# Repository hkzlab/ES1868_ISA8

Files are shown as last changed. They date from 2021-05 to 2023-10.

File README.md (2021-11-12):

# ES1868F 8bit ISA Sound Card

## Introduction

This is a sound card for the ISA 8bit bus sporting the **ES1868F** chip by *ESS Technology*.

This chip provides **Sound Blaster PRO 2.0** (stereo), **OPL3** compatibility (via *ESFM*), MPU-401 support and is considered one of the [best chips](https://www.philscomputerlab.com/ess-audiodrive-es1868.html) used in clone cards.

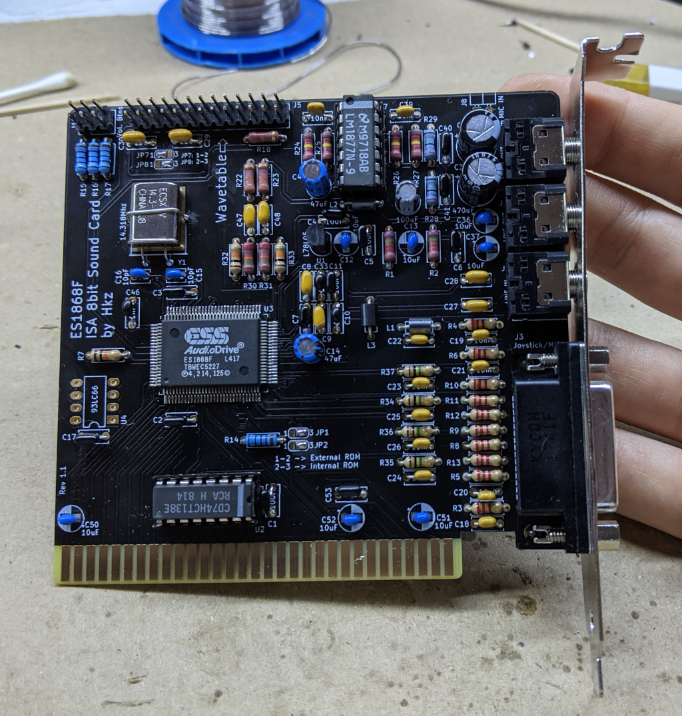
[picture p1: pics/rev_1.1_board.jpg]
Rev. 1.1 Board


This board provides the following connections:

* Speaker out (amplified)
* Line out
* Line in
* AUX in (internal header, since rev 1.2)
* Microphone in (internal header)
* Joystick port
* MIDI on Joystick port
* Wavetable header
* Volume control header

### Disclaimer

I take NO responsibility for what happens if you decide to build and use this card. Your computer might crash, catch fire or be destroyed in other nasty ways.
You're encourauged to take what you deem fit from this, and use it in your projects!

### Functionalities

✅ means I tested the functionality and it works, ❌ means I tested the functionality and found issues, ? means that the functionality has yet to be tested.

* [✅] FM Synthesis via OPL3 clone (**ESFM**)
* [✅] Digital audio playback
* [✅] Stereo (left/right channel) check (Tested with Sound Blaster PRO Test program, digitized sound mode)
* [✅] Joystick port
* [✅] Speaker Out (amplified)
* [✅] Line out
* [✅] Line in
* [✅] AUX In
* [?] Microphone in
* [✅] MIDI output via Joystick port (tested using DOSMID MPU mode on a Roland SC55)
* [✅] Wavetable daughterboard

The card was tested on:

* [✅] 286 16Mhz / DOS 6.22
* [✅] NEC V20 9.54Mhz / DOS 6.22 (Use **UNISOUND**, see **Configuration** section below)
* [✅] NEC V20 4.77Mhz / DOS 6.22 (Use **UNISOUND**, see **Configuration** section below)
* [✅] 8088 8Mhz / DOS 6.22 (Use **UNISOUND**, see **Configuration** section below)
* [✅] 8088 4.77Mhz / DOS 6.22 (Use **UNISOUND**, see **Configuration** section below)
* [✅] 486DX 40Mhz / DOS 7.1 (Use **UNISOUND**, see **Configuration** section below)
* [✅] Am5x86 40/160Mhz / DOS 7.1 (Use **UNISOUND**, see **Configuration** section below)

## Configuration

This card is jumperless and must be configured before use.
Under DOS you can us the [ESSCFG](software/ESSCFG.EXE) tool and tweak the volume via [ESSVOL](software/ESSVOL.EXE).

The **recommended** way to do this (especially under a very slow machine, like a V20/8088) is by using the [UNISOUND](https://www.vogons.org/viewtopic.php?f=62&t=72553) configurator.

It's important to add the `/XEA` parameter to `UNISOUND.COM` when using it, and remember to execute it after setting the `BLASTER` environment variable, for example with the command `SET BLASTER=A220 I5 D1 P330 T5 J201` (clearly changing the parameters depending on your setup).

**WARNING**: If you use an XT-IDE adapter at the default base address (300h), remember to set the MPU-401 base for this card to something else (like 330h)!

## Bill of Materials

**TODO**

Value of L1/L2/L3 ferrite beads is non critical. I used [these](https://www.mouser.it/ProductDetail/623-2743001112LF).

## Known Issues

### Rev 1.0

* Joystick plug "J3" silkscreen overlaps with some resistors (fixed in 1.1).
* The thread in the audio jacks I'm using (Kycon STX-3100-3CB) is flush with the bracket, so if the bracket has some bending, the plug risks to be pushed away (fixed in 1.1 by moving the connectors 0,5mm towards the edge).

## Credits

Thanks to [Sergey Kiselev](https://github.com/skiselev) for his symbol/footprint library!

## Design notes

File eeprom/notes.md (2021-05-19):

# PnP EEPROM format

This is all the datasheet has to say regarding the ES1868F EEPROM format:

```text
'A5'		Sync Byte
IRQB IRQA	Mapping for IRQB/A
IRQD IRQC	Mapping for IRQD/C
IRQF IRQE	Mapping for IRQF/E
DRQB DRQA	Mapping for DRQB/A
DRQD DRQC	Mapping for DRQD/C
PNP Reg 25h
PNP Reg 26h
```

An example is then provided:

```text
; *********************************************************
;
; Start of ESS Proprietary Header (8 bytes)
;
; *********************************************************
0A5H; PNP OK byte
059H; IRQA = 9 IRQB = 5
0A7H; IRQC = 7 IRQD = 10
0CBH; IRQE = 11 IRQF = 12
010H; DRQA = 0 DRQB = 1
053H; DRQC = 3 DRQD = 5
002H; MPU-401 part of audio, CD, DRQ latching off
00CH; GPO1/GPI are not used by Modem DMA channel or g.p.

; *********************************************************
;
; Start of PNP Resource Header
;
; *********************************************************
016H, 073H, 018H, 068H; "ESS1868" product id for ES1868
0FFH, 0FFH, 0FFH, 0FFH; serial number FFFFFFFF (not supported)
000H; header checksum
00AH, 010H, 010H; PNP 1.0, ESS version 1.0
082H, 023H, 000H; “ESS ES1868 Plug and Play AudioDrive”

; *******************************************************
;
; LOGICAL DEVICE 0 -- Configuration Ports
; 8 bytes at any I/O address that is a multiple of 8
;
; *******************************************************
015H, 016H, 073H, 000H, 000H, 000H; ESS0000
047H, 001H, 000H, 008H, 0F8H, 00FH, 008H, 008H; 800H-FF8H 8 bytes

; *******************************************************
;
; LOGICAL DEVICE 1 -- Audio Controller w/FM and MPU-401
;
; *******************************************************
015H, 016H, 073H, 018H, 068H, 000H; ESS1868

; Basic configuration 0000
031H, 000H
02AH, 002H, 008H; DMA 0: DRQ 1
02AH, 009H, 008H; DMA 1: DRQ 0 or 3
022H, 020H, 000H; INT 0: IRQ 5
04BH, 020H, 002H, 010H; 220-22F 16 bytes
04BH, 088H, 003H, 004H; 388-38B
04BH, 030H, 003H, 002H; 330-331

; Basic configuration 0001
031H, 001H
02AH, 002H, 008H; DMA 0: DRQ 1
02AH, 009H, 008H; DMA 1: DRQ 0 or 3
022H, 0A0H, 006H; INT 0: IRQ 5, 7, 9, or 10
047H, 001H, 020H, 002H, 040H, 002H, 020H, 010H; 220 or 240 16 bytes
04BH, 088H, 003H, 004H; 388-38B
047H, 001H, 000H, 003H, 030H, 003H, 030H, 002H; 300 or 330 2 bytes

; Basic configuration 0002
031H, 001H
02AH, 00BH, 008H; DMA 0: DRQ 0, 1 or 3
02AH, 00BH, 008H; DMA 1: DRQ 0, 1 or 3
022H, 0A0H, 01EH; INT 0: IRQ 5, 7, 9, 10, 11, or 12
047H, 001H, 020H, 002H, 080H, 002H, 020H, 010H; 220, 240, 260, 280 16 bytes
04BH, 088H, 003H, 004H; 388-38B
047H, 001H, 000H, 003H, 030H, 003H, 030H, 002H; 330 or 330 2 bytes

; Basic configuration 0003
031H, 001H
002H, 00BH, 008H; DMA 0: DRQ 0, 1 or 3
02AH, 00BH, 008H; DMA 1: DRQ 0, 1 or 3
022H, 0A0H, 01EH; INT 0: IRQ 5, 7, 9, 10, 11, or 12
047H, 001H, 020H, 002H, 080H, 002H, 020H, 010H; 220, 240, 260, 280 16 bytes
04BH, 088H, 003H, 004H; 388-38B
047H, 001H, 000H, 008H, 0FEH, 00FH, 002H, 002H; 800/801-FFE/FFF 2 bytes

; Basic configuration 0004
031H, 002H
02AH, 00BH, 008H; DMA 0: DRQ 0, 1 or 3
02AH, 00BH, 008H; DMA 1: DRQ 0, 1 or 3
022H, 0A0H, 01EH; INT 0: IRQ 5, 7, 9, 10, 11, or 12
047H, 001H, 020H, 002H, 080H, 002H, 020H, 010H; 220, 240, 260, 280 16 bytes
047H, 001H, 000H, 008H, 0FCH, 00FH, 004H, 004H; 800/804-FFC/FFF 4 bytes
047H, 001H, 000H, 008H, 0FEH, 00FH, 002H, 002H; 800/801-FFE/FFF 2 bytes

038H; end configurations

; *******************************************************
;
; LOGICAL DEVICE 2 -- Joystick
; Only choice is one address at 201.
;
; *******************************************************
015H, 016H, 073H, 000H, 001H, 000H; ESS0001

; Basic configuration 0000
031H, 000H
04BH, 001H, 002H, 001H; 201
; Windows95 joystick driver will only allow 200-20F!!!
; Basic configuration 0001
031H, 001H
047H, 001H, 000H, 002H, 00FH, 002H, 001H, 001H; 200/200-20F/20F 1 byte
038H; end dependent functions
01CH, 041H, 0D0H, 0B0H, 02FH; Compatible ID: PNPB02F

; *******************************************************
;
; LOGICAL DEVICE 3 -- IDE CD-ROM
; needs an IRQ (10, 11, or 12) and two separate address ranges
;
; *******************************************************
015H, 016H, 073H, 000H, 002H, 000H; ESS0002

; Basic configuration 0000
031H, 000H
022H, 000H, 010H; IRQ 12
04BH, 068H, 001H, 008H; 168-16F 8 bytes
04BH, 06EH, 003H, 002H; 36E-36F 2 bytes
; Basic configuration 0001

031H, 001H
022H, 000H, 00CH; IRQ 10 or 11
04BH, 068H, 001H, 008H; 168-16F 8 bytes
04BH, 06EH, 003H, 002H; 36E-36F 2 bytes

; Basic configuration 0002
031H, 001H
022H, 000H, 01CH; IRQ 10, 11 or 12
04BH, 0E8H, 001H, 008H; 1E8-1EF 8 bytes
04BH, 0EEH, 003H, 002H; 3EE-3EF 2 bytes

; Basic configuration 0003
031H, 001H
022H, 000H, 01CH; IRQ 10, 11 or 12
047H, 001H, 000H, 001H, 0F8H, 001H, 008H, 008H; 100/1F8-107/1FF 8 bytes
047H, 001H, 000H, 003H, 0FEH, 003H, 002H, 002H; 300/301-3FE/3FF 2 bytes

038H; end dependent functions

01CH, 041H, 0D0H, 006H, 000H	; Compatible ID: PNP0600
079H, 000H; end tag + checksum
```

## Default configuration

## Files

The default configuration that my generic board takes from startup is the following:

- Address: 220h
- IRQ: 1
- DMA: 0
- Secondary DMA: 0
- MPU401: 300h
- Joystick: Enabled

### AT93C66-dump.bin

A dump of the PnP ROM taken from a generic no-name board.

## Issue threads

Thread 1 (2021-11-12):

Values for L1, L2, and L3 are just listed as filter

washyu, 2021-11-12:
In the schematic and on the silkscreen the value is just listed as Filter.  Could you please supply the value i really want to finish building this card but I am stuck because of this.

hkzlab, 2021-11-12:
As shown on the schematics and in photo those are ferrite beads. Value is absolutely non critical, a simple jumper made with the leg of a resistor would probably work.
You can use these: https://www.mouser.it/ProductDetail/623-2743001112LF

Closed 2021-11-12.

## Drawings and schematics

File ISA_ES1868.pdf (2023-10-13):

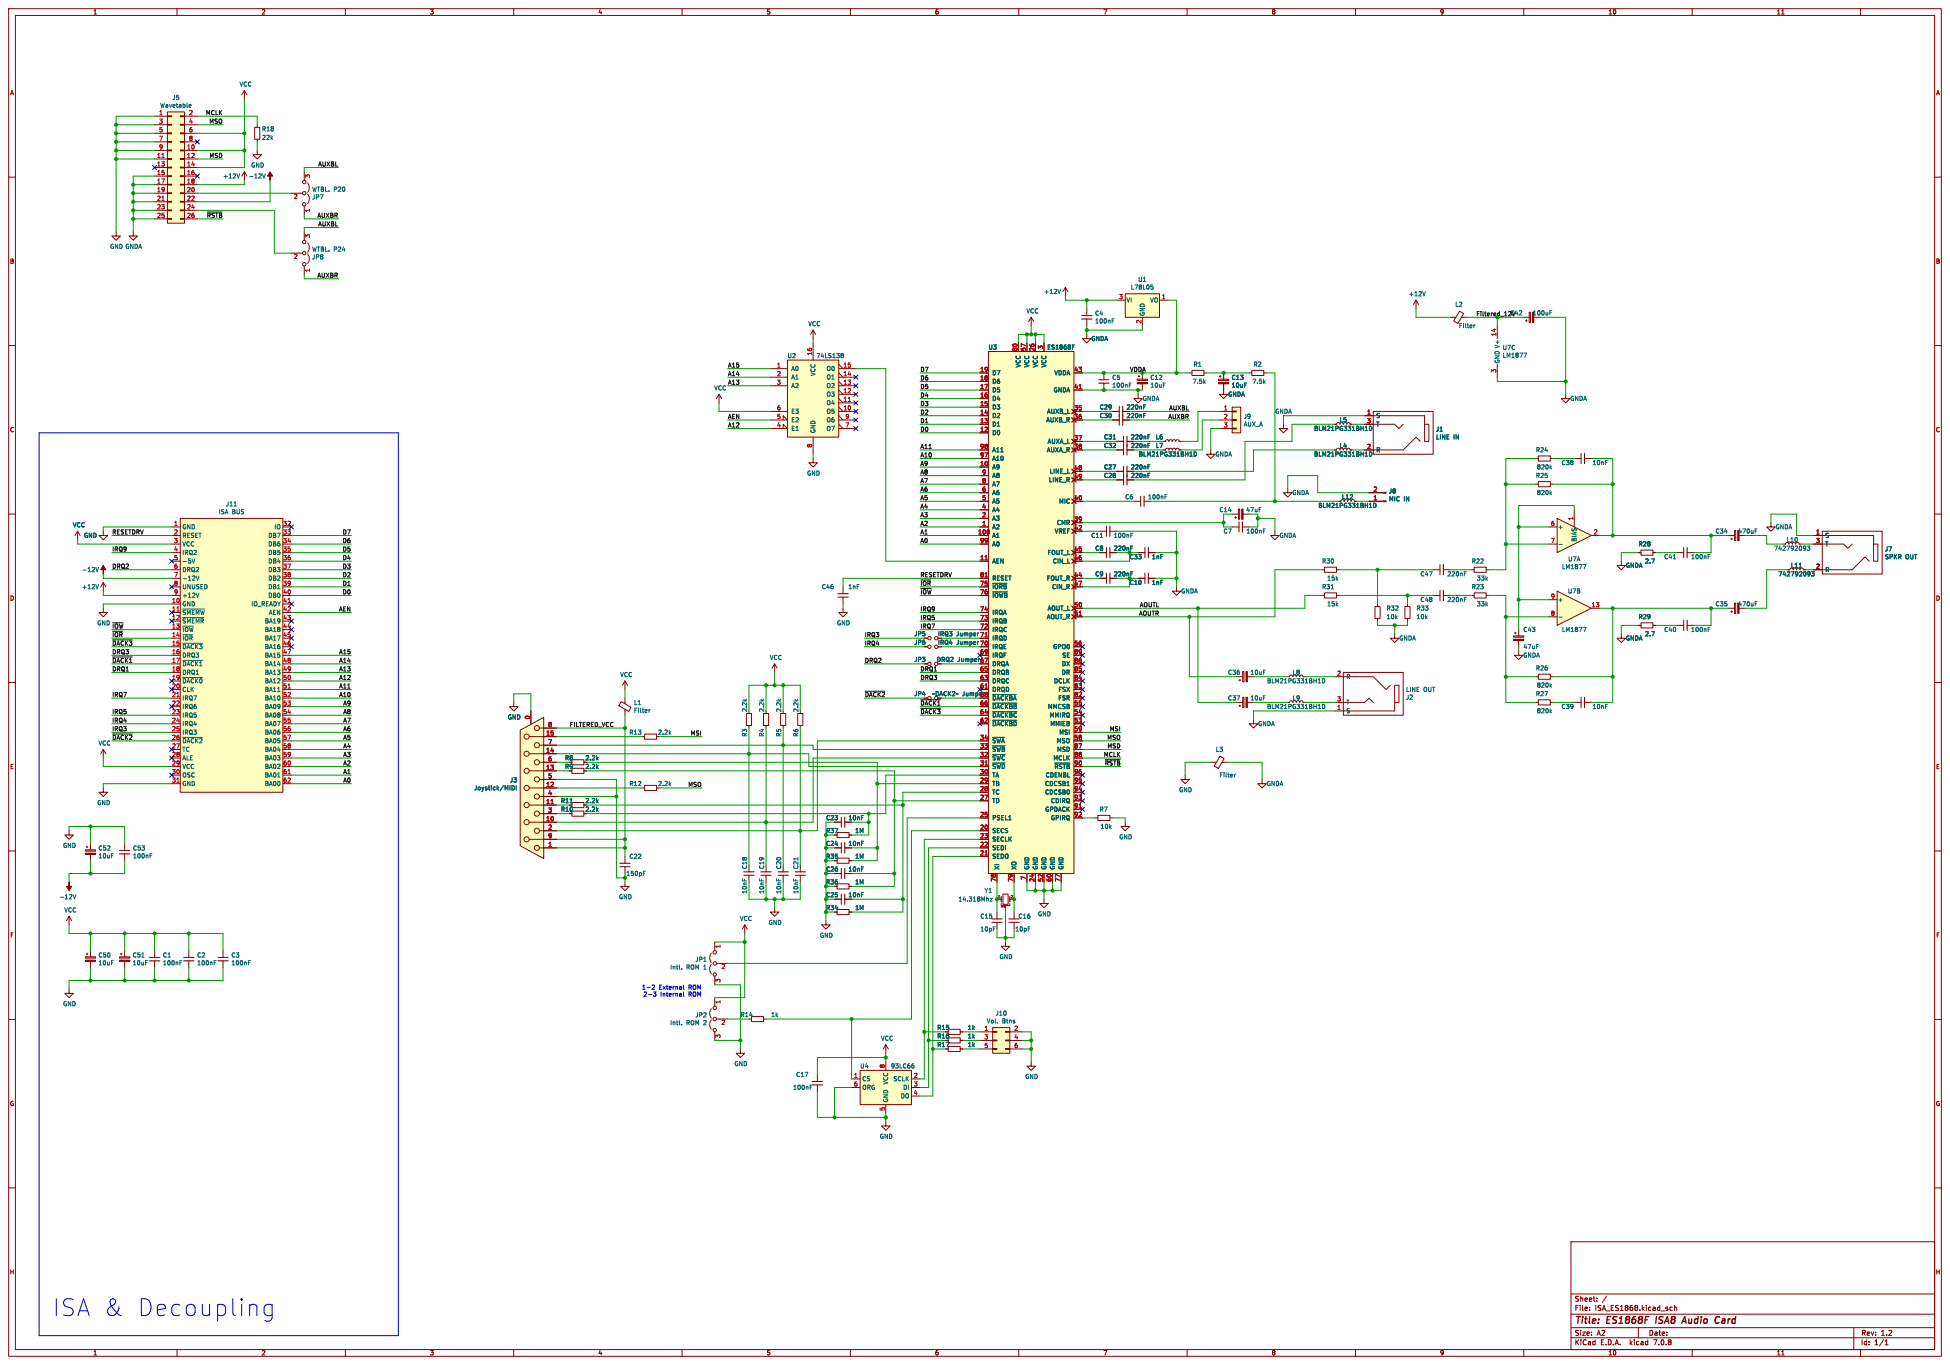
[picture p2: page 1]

3 TA 30 ~{SWD} 31 ~{SWC} 32 ~{SWB} 33 ~{SWA} 34

ISA BUS
GND 1 GND 10 ~{SMEMW} 11 ~{SMEMR} 12 ~{IOW} 13 ~{IOR} 14 ~{DACK3} 15 DRQ3 16 ~{DACK1} 17 DRQ1 18 ~{DACK0} 19 RESET 2 CLK 20
IRQ3 25 ~{DACK2} 26 TC 27 ALE 28 VCC 29 VCC 3 OSC 30 GND 31
IO_READY 41 AEN 42 BA19 43 BA18 44 BA17 45 BA16 46 BA15 47 BA14 48 BA13 49

~{RSTB} MCLK MSI MSD MSO

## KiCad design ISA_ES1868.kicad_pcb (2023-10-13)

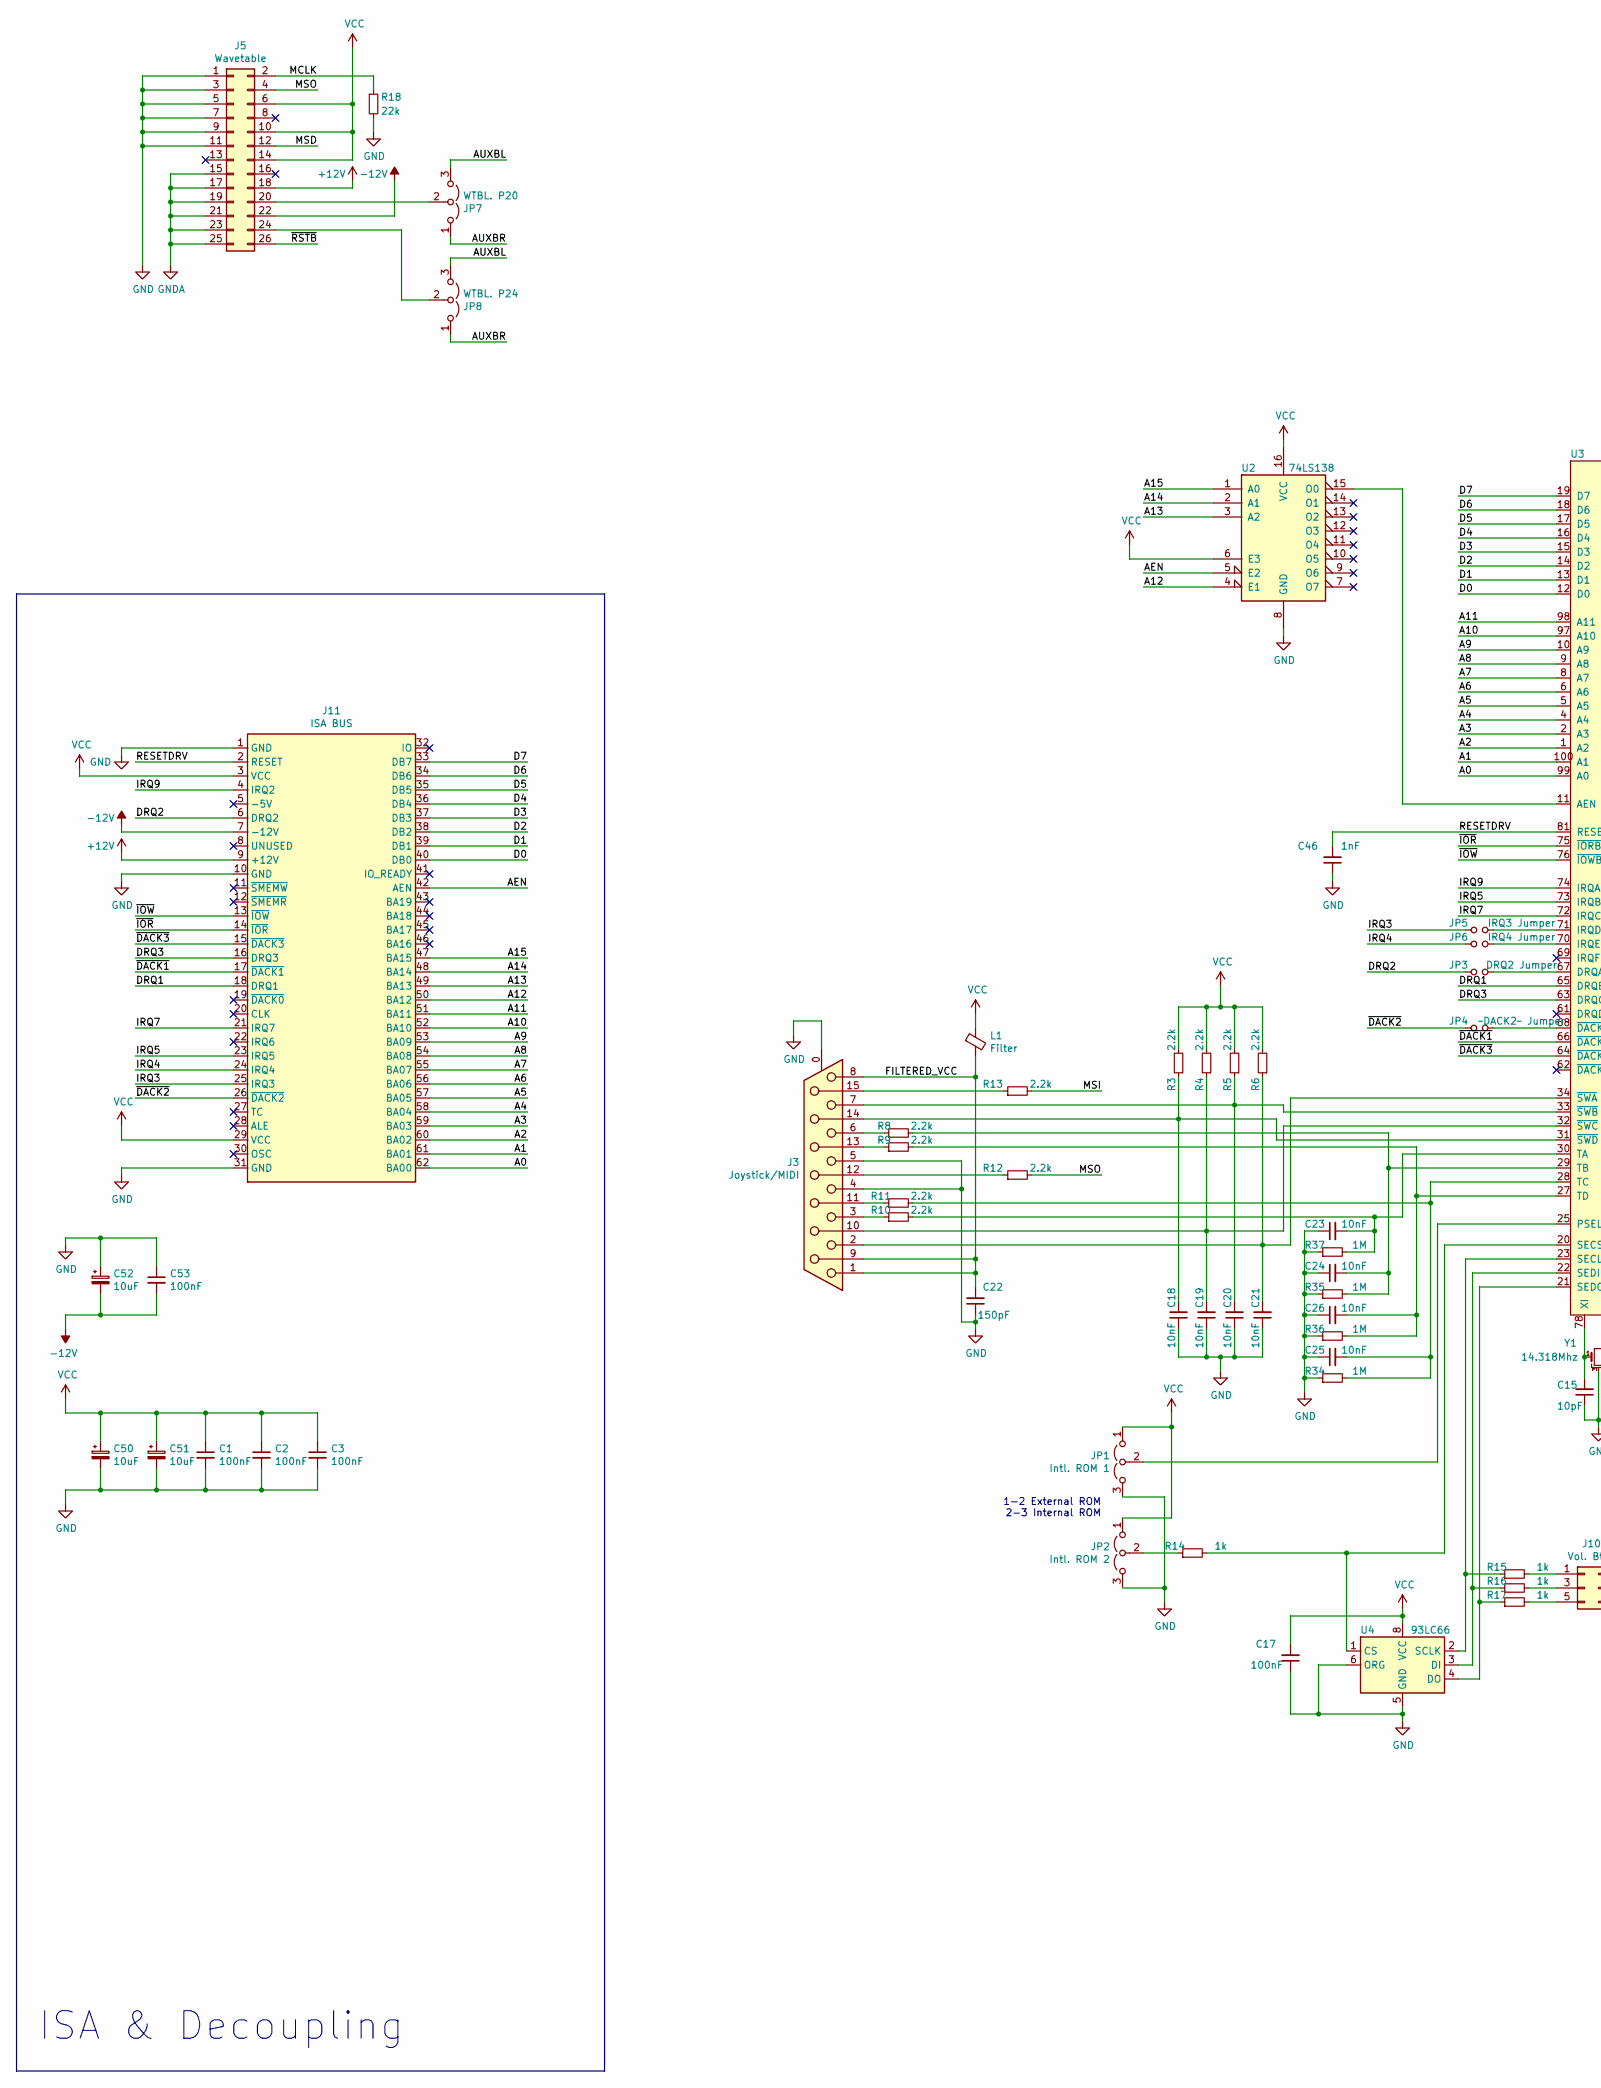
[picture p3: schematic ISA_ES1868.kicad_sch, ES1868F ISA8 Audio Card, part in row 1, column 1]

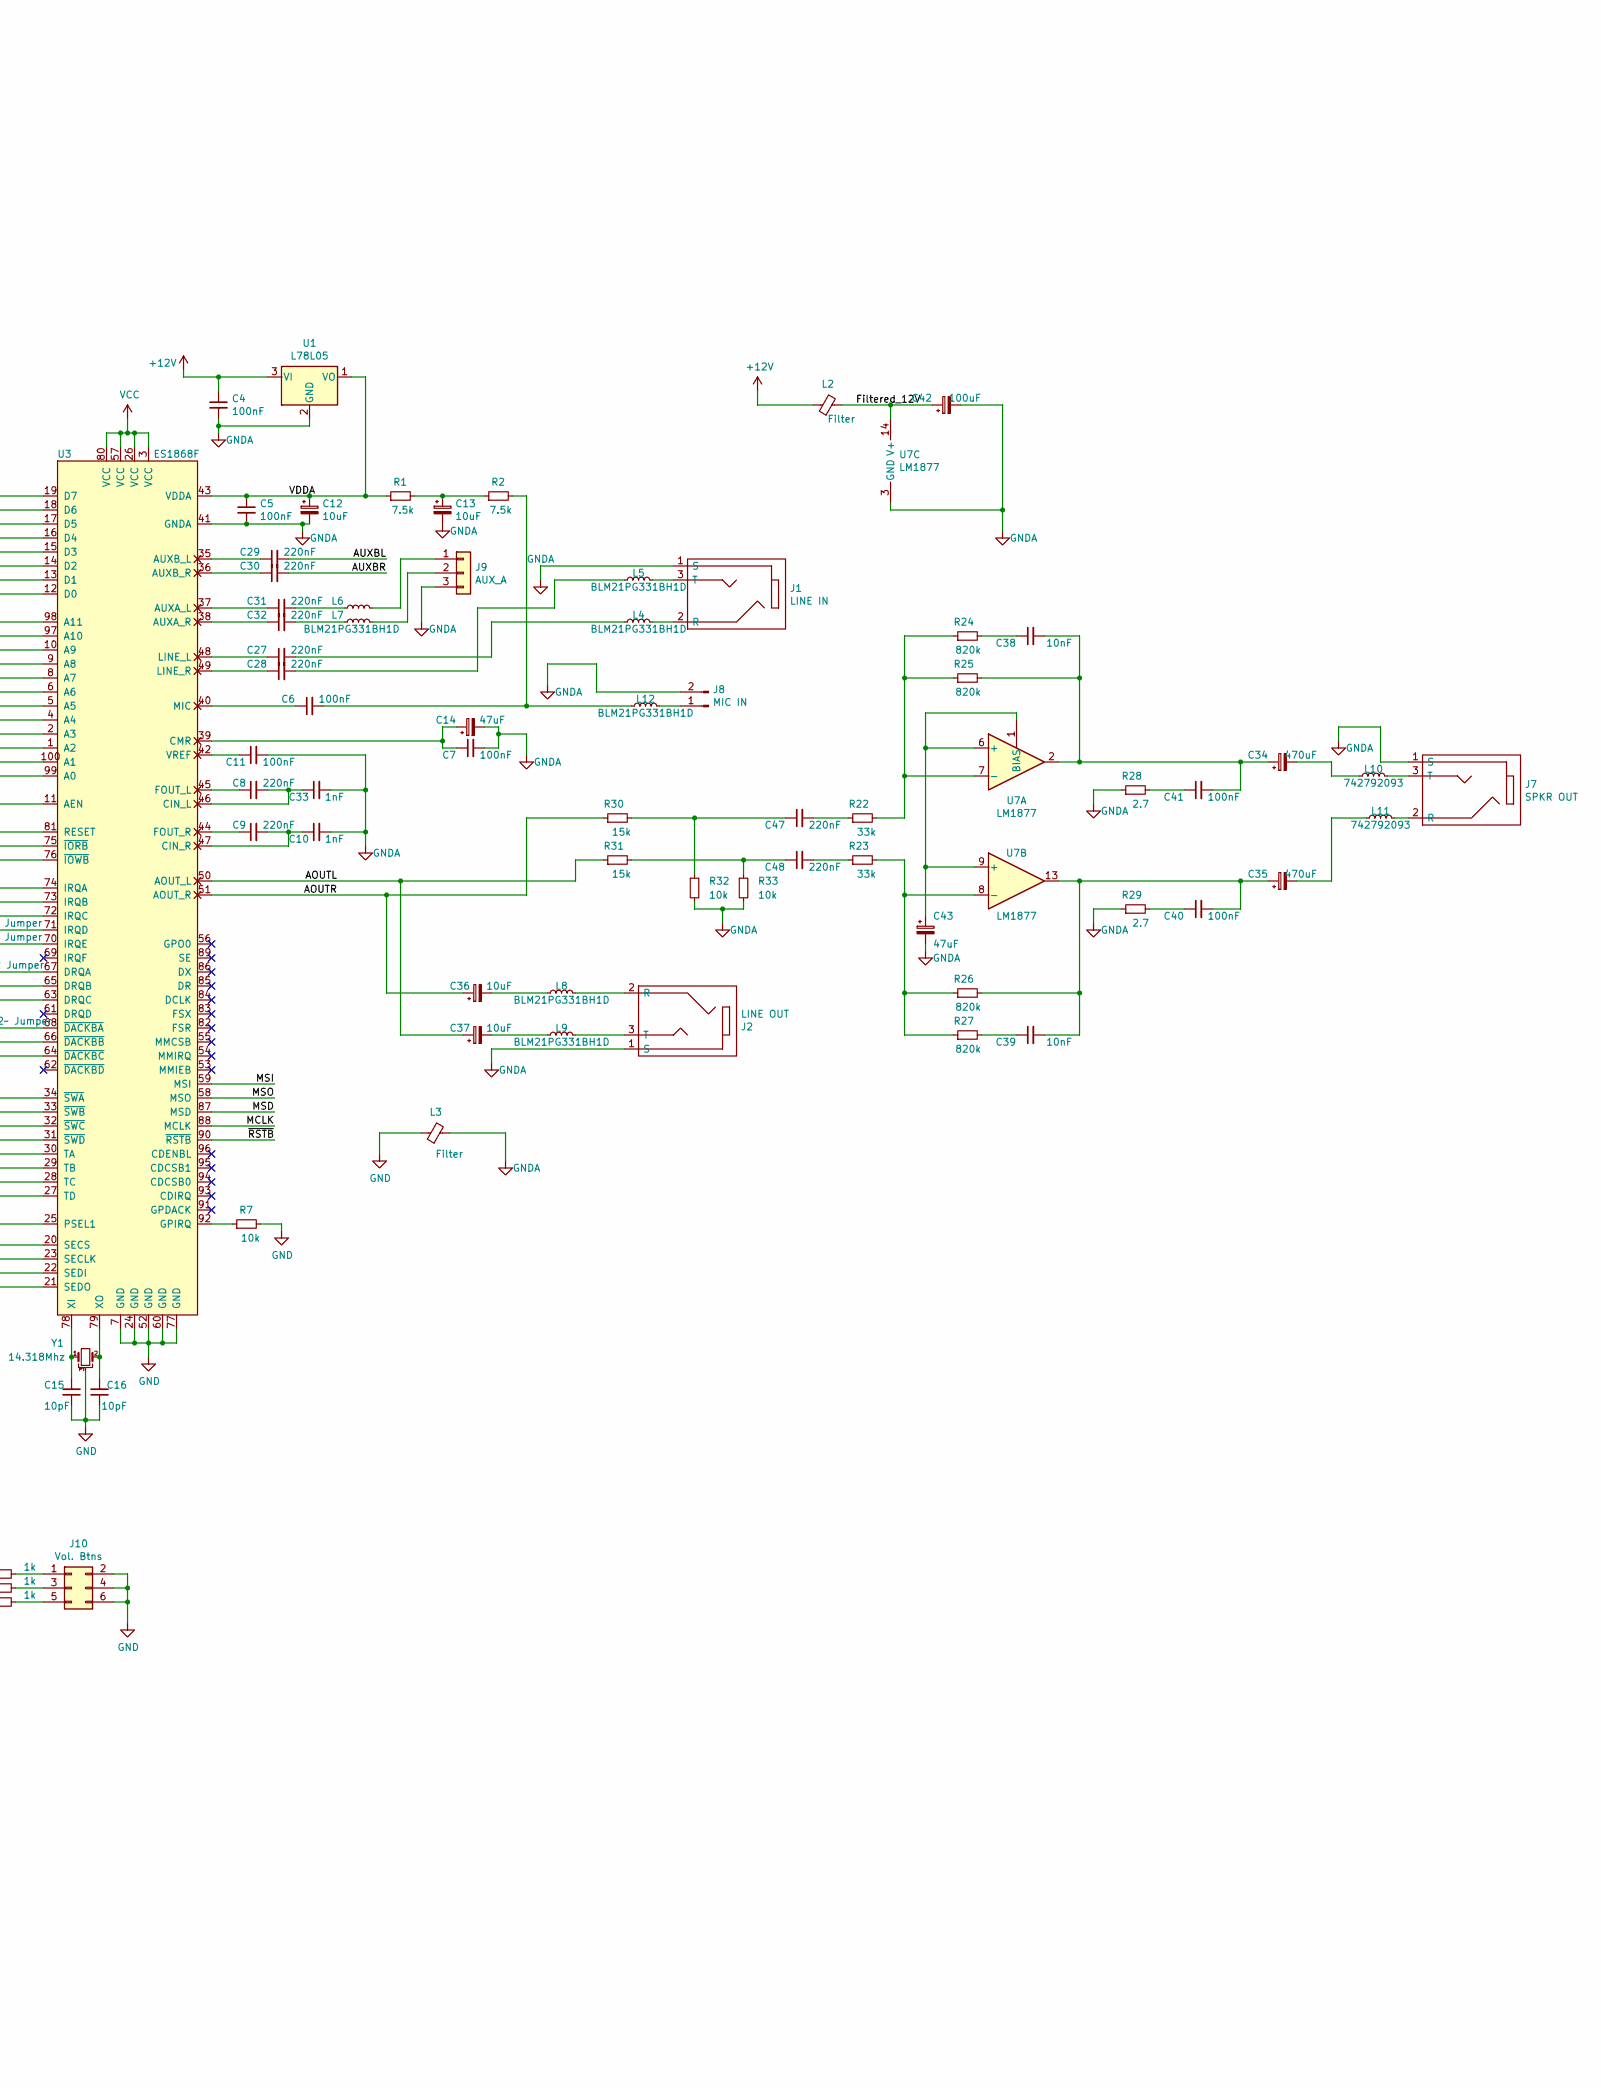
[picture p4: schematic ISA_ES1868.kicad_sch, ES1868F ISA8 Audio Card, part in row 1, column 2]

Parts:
C1, C2, C3, C4, C5, C6, C7, C11, C17, C40, C41, C53: 100nF; C_Disc_D6.0mm_W2.5mm_P5.00mm
C8, C9, C27, C28, C29, C30, C31, C32, C47, C48: 220nF; C_Disc_D6.0mm_W2.5mm_P5.00mm
C10, C33, C46: 1nF; C_Disc_D6.0mm_W2.5mm_P5.00mm
C12, C13, C36, C37, C50, C51, C52: 10uF; CP_Radial_D5.0mm_P2.50mm
C14, C43: 47uF; CP_Radial_D5.0mm_P2.50mm
C15, C16: 10pF; C_Disc_D3.8mm_W2.6mm_P2.50mm
C18, C19, C20, C21, C23, C24, C25, C26, C38, C39: 10nF; C_Disc_D6.0mm_W2.5mm_P5.00mm
C22: 150pF; C_Disc_D6.0mm_W2.5mm_P5.00mm
C34, C35: 470uF; CP_Radial_D8.0mm_P3.50mm
C42: 100uF; CP_Radial_D5.0mm_P2.50mm
J1: LINE IN; Conn_Audio_3.5mm_Stereo_SJ1-352XNG
J2: LINE OUT; Conn_Audio_3.5mm_Stereo_SJ1-352XNG
J3: Joystick/MIDI; SB_DB15_152-3415
J5: Wavetable; PinHeader_2x13_P2.54mm_Vertical
J7: SPKR OUT; Conn_Audio_3.5mm_Stereo_SJ1-352XNG
J8: MIC IN; PinHeader_1x02_P2.54mm_Horizontal
J9: AUX_A; PinHeader_1x03_P2.54mm_Vertical
J10: Vol. Btns; PinHeader_2x03_P2.54mm_Vertical
J11: ISA BUS; Conn_Edge_PCB_ISA8
JP1: Intl. ROM 1; SolderJumper-3_P1.3mm_Open_RoundedPad1.0x1.5mm_NumberLabels
JP2: Intl. ROM 2; SolderJumper-3_P1.3mm_Open_RoundedPad1.0x1.5mm_NumberLabels
JP3: DRQ2 Jumper; SolderJumper-2_P1.3mm_Open_RoundedPad1.0x1.5mm
JP4: ~DACK2~ Jumper; SolderJumper-2_P1.3mm_Open_RoundedPad1.0x1.5mm
JP5: IRQ3 Jumper; SolderJumper-2_P1.3mm_Open_RoundedPad1.0x1.5mm
JP6: IRQ4 Jumper; SolderJumper-2_P1.3mm_Open_RoundedPad1.0x1.5mm
JP7: WTBL. P20; SolderJumper-3_P1.3mm_Open_RoundedPad1.0x1.5mm_NumberLabels
JP8: WTBL. P24; SolderJumper-3_P1.3mm_Open_RoundedPad1.0x1.5mm_NumberLabels
L1, L2, L3: Filter; L_Axial_L5.3mm_D2.2mm_P7.62mm_Horizontal_Vishay_IM-1
L4, L5, L6, L7, L8, L9, L12: BLM21PG331BH1D; L_0805_2012Metric_Pad1.15x1.40mm_HandSolder
L10, L11: 742792093; L_0805_2012Metric_Pad1.15x1.40mm_HandSolder
R1, R2: 7.5k; R_Axial_DIN0207_L6.3mm_D2.5mm_P7.62mm_Horizontal
R3, R4, R5, R6, R8, R9, R10, R11, R12, R13: 2.2k; R_Axial_DIN0207_L6.3mm_D2.5mm_P7.62mm_Horizontal
R7, R32, R33: 10k; R_Axial_DIN0207_L6.3mm_D2.5mm_P7.62mm_Horizontal
R14, R15, R16, R17: 1k; R_Axial_DIN0207_L6.3mm_D2.5mm_P7.62mm_Horizontal
R18: 22k; R_Axial_DIN0207_L6.3mm_D2.5mm_P7.62mm_Horizontal
R22, R23: 33k; R_Axial_DIN0207_L6.3mm_D2.5mm_P7.62mm_Horizontal
R24, R25, R26, R27: 820k; R_Axial_DIN0207_L6.3mm_D2.5mm_P7.62mm_Horizontal
R28, R29: 2.7; R_Axial_DIN0207_L6.3mm_D2.5mm_P7.62mm_Horizontal
R30, R31: 15k; R_Axial_DIN0207_L6.3mm_D2.5mm_P7.62mm_Horizontal
R34, R35, R36, R37: 1M; R_Axial_DIN0207_L6.3mm_D2.5mm_P7.62mm_Horizontal
U1: L78L05; TO-92_Inline
U2: 74LS138; DIP-16_W7.62mm_LongPads
U3: ES1868F; LQFP-14x20mm_P0.5mm
U4: 93LC66; DIP-8_W7.62mm_LongPads
U7: LM1877; DIP-14_W7.62mm_LongPads
Y1: 14.318Mhz; Crystal_HC49-U_Horizontal_1EP_style2

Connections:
+12V: C4.1, J5.18, J11.9 (+12V), L2.1, U1.3 (VI)
-12V: C52.2, C53.2, J5.22, J11.7 (-12V)
/A0: J11.62 (BA00), U3.99 (A0)
/A1: J11.61 (BA01), U3.100 (A1)
/A2: J11.60 (BA02), U3.1 (A2)
/A3: J11.59 (BA03), U3.2 (A3)
/A4: J11.58 (BA04), U3.4 (A4)
/A5: J11.57 (BA05), U3.5 (A5)
/A6: J11.56 (BA06), U3.6 (A6)
/A7: J11.55 (BA07), U3.8 (A7)
/A8: J11.54 (BA08), U3.9 (A8)
/A9: J11.53 (BA09), U3.10 (A9)
/A10: J11.52 (BA10), U3.97 (A10)
/A11: J11.51 (BA11), U3.98 (A11)
/A12: J11.50 (BA12), U2.4 (E1)
/A13: J11.49 (BA13), U2.3 (A2)
/A14: J11.48 (BA14), U2.2 (A1)
/A15: J11.47 (BA15), U2.1 (A0)
/AEN: J11.42 (AEN), U2.5 (E2)
/AOUTL: C37.1, R31.1, U3.50 (AOUT_L)
/AOUTR: C36.1, R30.1, U3.51 (AOUT_R)
/AUXBL: C29.2, JP7.3 (B), JP8.3 (B)
/AUXBR: C30.2, JP7.1 (A), JP8.1 (A)
/D0: J11.40 (DB0), U3.12 (D0)
/D1: J11.39 (DB1), U3.13 (D1)
/D2: J11.38 (DB2), U3.14 (D2)
/D3: J11.37 (DB3), U3.15 (D3)
/D4: J11.36 (DB4), U3.16 (D4)
/D5: J11.35 (DB5), U3.17 (D5)
/D6: J11.34 (DB6), U3.18 (D6)
/D7: J11.33 (DB7), U3.19 (D7)
/DRQ1: J11.18 (DRQ1), U3.65 (DRQB)
/DRQ2: J11.6 (DRQ2), JP3.1
/DRQ3: J11.16 (DRQ3), U3.63 (DRQC)
/FILTERED_VCC: C22.2, J3.1, J3.8, J3.9, L1.2
/Filtered_12V: C42.1, L2.2, U7.14 (V+)
/IRQ3: J11.25 (IRQ3), JP5.1
/IRQ4: J11.24 (IRQ4), JP6.1
/IRQ5: J11.23 (IRQ5), U3.73 (IRQB)
/IRQ7: J11.21 (IRQ7), U3.72 (IRQC)
/IRQ9: J11.4 (IRQ2), U3.74 (IRQA)
/MCLK: J5.2, R18.1, U3.88 (MCLK)
/MSD: J5.12, U3.87 (MSD)
/MSI: R13.2, U3.59 (MSI)
/MSO: J5.4, R12.2, U3.58 (MSO)
/RESETDRV: C46.2, J11.2 (RESET), U3.81 (RESET)
/VDDA: C5.1, C12.1, R1.1, U1.1 (VO), U3.43 (VDDA)
/~DACK1: J11.17 (~DACK1), U3.66 (~DACKBB)
/~DACK2: J11.26 (~DACK2), JP4.1
/~DACK3: J11.15 (~DACK3), U3.64 (~DACKBC)
/~IOR: J11.14 (~IOR), U3.75 (~IORB)
/~IOW: J11.13 (~IOW), U3.76 (~IOWB)
/~RSTB: J5.26, U3.90 (~RSTB)
GND: C1.2, C2.2, C3.2, C15.1, C16.1, C17.1, C18.1, C19.1, C20.1, C21.1, C22.1, C23.1, C24.1, C25.1, C26.1, C46.1, C50.2, C51.2, C52.1, C53.1, J3.0 (PAD), J3.4, J3.5, J5.1, J5.3, J5.5, J5.7, J5.9, J5.11, J10.2, J10.4, J10.6, J11.1 (GND), J11.10 (GND), J11.31 (GND), JP1.3 (B), JP2.3 (B), L3.1, R7.2, R18.2, R34.1, R35.1, R36.1, R37.1, U2.8 (GND), U3.7 (GND), U3.24 (GND), U3.52 (GND), U3.60 (GND), U3.77 (GND), U4.5 (GND), U4.6 (ORG), Y1.3
GNDA: C4.2, C5.2, C7.2, C10.2, C11.2, C12.2, C13.2, C14.2, C33.2, C42.2, C43.2, J1.1 (S), J2.1 (S), J5.15, J5.17, J5.19, J5.21, J5.23, J5.25, J7.1 (S), J8.2, J9.3, L3.2, R28.1, R29.1, R32.2, R33.2, U1.2 (GND), U3.41 (GNDA), U7.3 (GND), U7.4 (GND), U7.5 (GND), U7.10 (GND), U7.11 (GND), U7.12 (GND)
unnamed: C6.1, U3.40 (MIC)
unnamed: C6.2, L12.2, R2.2
unnamed: C8.1, U3.45 (FOUT_L)
unnamed: C9.1, U3.44 (FOUT_R)
unnamed: C9.2, C10.1, U3.47 (CIN_R)
unnamed: C11.1, U3.42 (VREF)
unnamed: C13.1, R1.2, R2.1
unnamed: C7.1, C14.1, U3.39 (CMR)
unnamed: C15.2, U3.78 (XI), Y1.1
unnamed: C16.2, U3.79 (XO), Y1.2
unnamed: C18.2, J3.14, R3.1, U3.31 (~SWD)
unnamed: C19.2, J3.10, R4.1, U3.32 (~SWC)
unnamed: C20.2, J3.7, R5.1, U3.33 (~SWB)
unnamed: C21.2, J3.2, R6.1, U3.34 (~SWA)
unnamed: C23.2, R10.2, R37.2, U3.30 (TA)
unnamed: C24.2, R8.2, R35.2, U3.29 (TB)
unnamed: C25.2, R11.2, R34.2, U3.28 (TC)
unnamed: C26.2, R9.2, R36.2, U3.27 (TD)
unnamed: C27.1, U3.48 (LINE_L)
unnamed: C27.2, L4.2
unnamed: C28.1, U3.49 (LINE_R)
unnamed: C28.2, L5.2
unnamed: C29.1, U3.35 (AUXB_L)
unnamed: C30.1, U3.36 (AUXB_R)
unnamed: C31.1, U3.37 (AUXA_L)
unnamed: C31.2, L6.2
unnamed: C32.1, U3.38 (AUXA_R)
unnamed: C32.2, L7.2
unnamed: C8.2, C33.1, U3.46 (CIN_L)
unnamed: C34.1, C38.2, C41.2, R25.2, U7.2
unnamed: C34.2, L10.2
unnamed: C35.1, C39.2, C40.2, R26.2, U7.13
unnamed: C35.2, L11.2
unnamed: C36.2, L8.2
unnamed: C37.2, L9.2
unnamed: C38.1, R24.2
unnamed: C39.1, R27.2
unnamed: C40.1, R29.2
unnamed: C41.1, R28.2
unnamed: C43.1, U7.1 (BIAS), U7.6 (+), U7.9 (+)
unnamed: C47.1, R30.2, R32.1
unnamed: C47.2, R22.1
unnamed: C48.1, R31.2, R33.1
unnamed: C48.2, R23.1
unnamed: J1.2 (R), L4.1
unnamed: J1.3 (T), L5.1
unnamed: J2.2 (R), L8.1
unnamed: J2.3 (T), L9.1
unnamed: J3.3, R10.1
unnamed: J3.6, R8.1
unnamed: J3.11 (P111), R11.1
unnamed: J3.12, R12.1
unnamed: J3.13, R9.1
unnamed: J3.15, R13.1
unnamed: J5.20, JP7.2 (C)
unnamed: J5.24, JP8.2 (C)
unnamed: J7.2 (R), L11.1
unnamed: J7.3 (T), L10.1
unnamed: J8.1, L12.1
unnamed: J9.1, L6.1
unnamed: J9.2, L7.1
unnamed: J10.1, R15.2
unnamed: J10.3, R16.2
unnamed: J10.5, R17.2
unnamed: JP1.2 (C), U3.25 (PSEL1)
unnamed: JP2.2 (C), R14.1
unnamed: JP3.2, U3.67 (DRQA)
unnamed: JP4.2, U3.68 (~DACKBA)
unnamed: JP5.2, U3.71 (IRQD)
unnamed: JP6.2, U3.70 (IRQE)
unnamed: R7.1, U3.92 (GPIRQ)
unnamed: R14.2, U3.20 (SECS), U4.1 (CS)
unnamed: R15.1, U3.23 (SECLK), U4.2 (SCLK)
unnamed: R16.1, U3.22 (SEDI), U4.3 (DI)
unnamed: R17.1, U3.21 (SEDO), U4.4 (DO)
unnamed: R22.2, R24.1, R25.1, U7.7 (-)
unnamed: R23.2, R26.1, R27.1, U7.8 (-)
unnamed: U2.15 (O0), U3.11 (AEN)
VCC: C1.1, C2.1, C3.1, C17.2, C50.1, C51.1, J5.6, J5.10, J5.14, J11.3 (VCC), J11.29 (VCC), JP1.1 (A), JP2.1 (A), L1.1, R3.2, R4.2, R5.2, R6.2, U2.6 (E3), U2.16 (VCC), U3.3 (VCC), U3.26 (VCC), U3.57 (VCC), U3.80 (VCC), U4.8 (VCC)

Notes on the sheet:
ISA & Decoupling
1-2 External ROM 2-3 Internal ROM

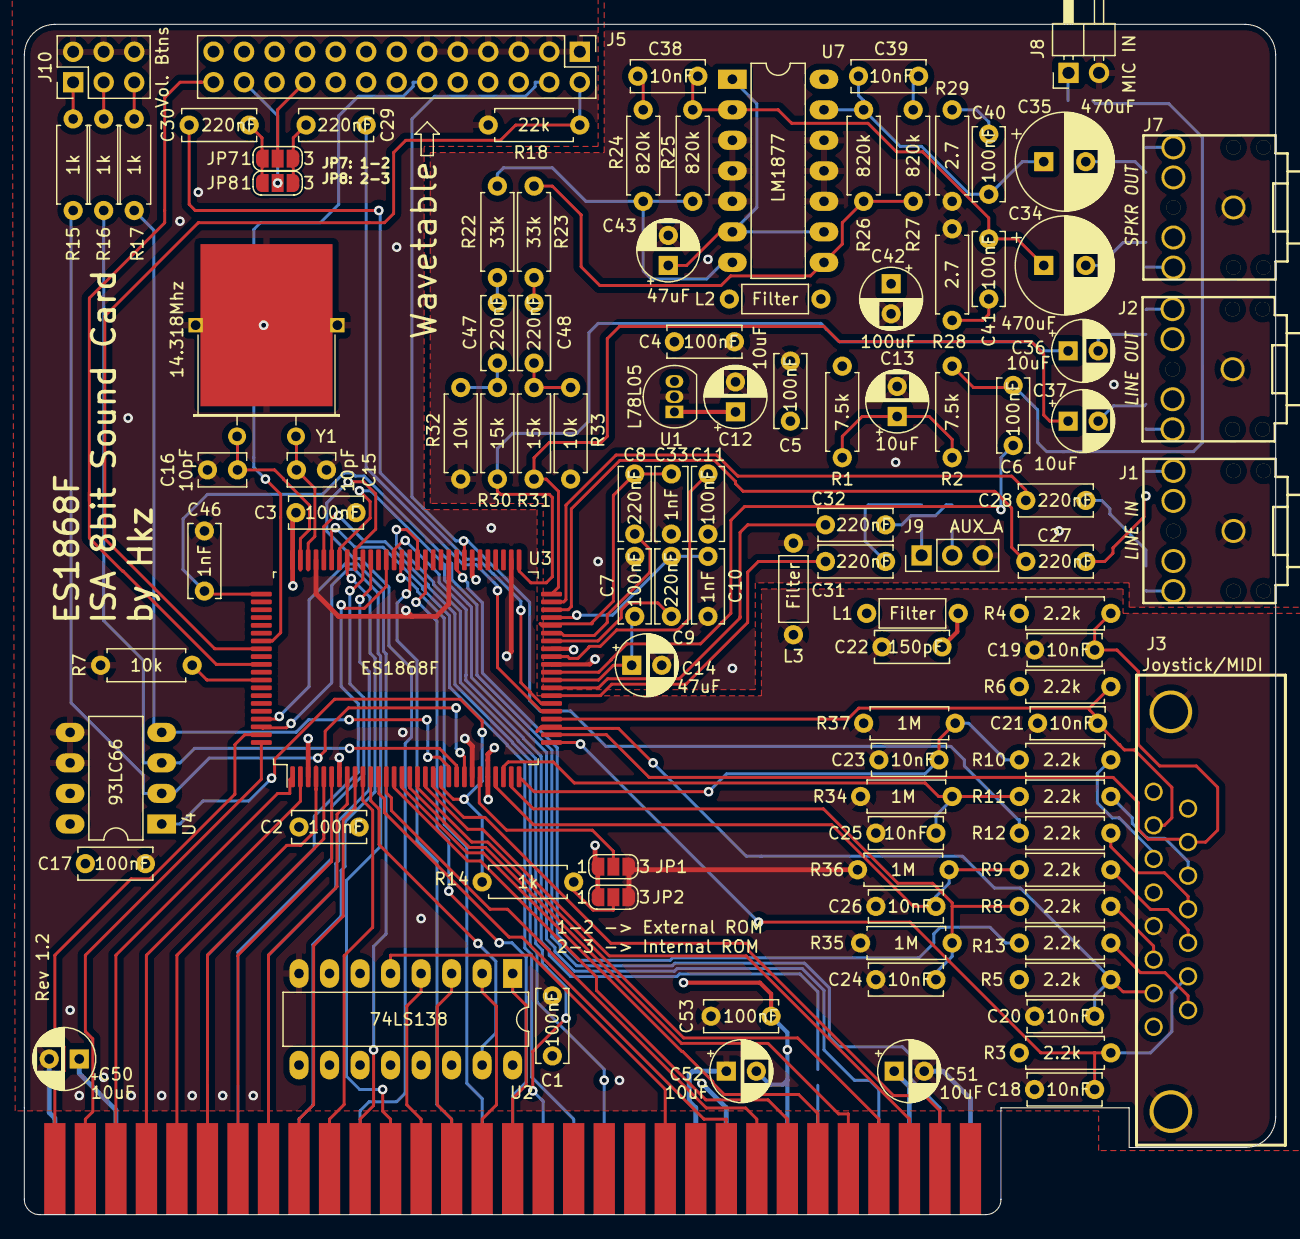
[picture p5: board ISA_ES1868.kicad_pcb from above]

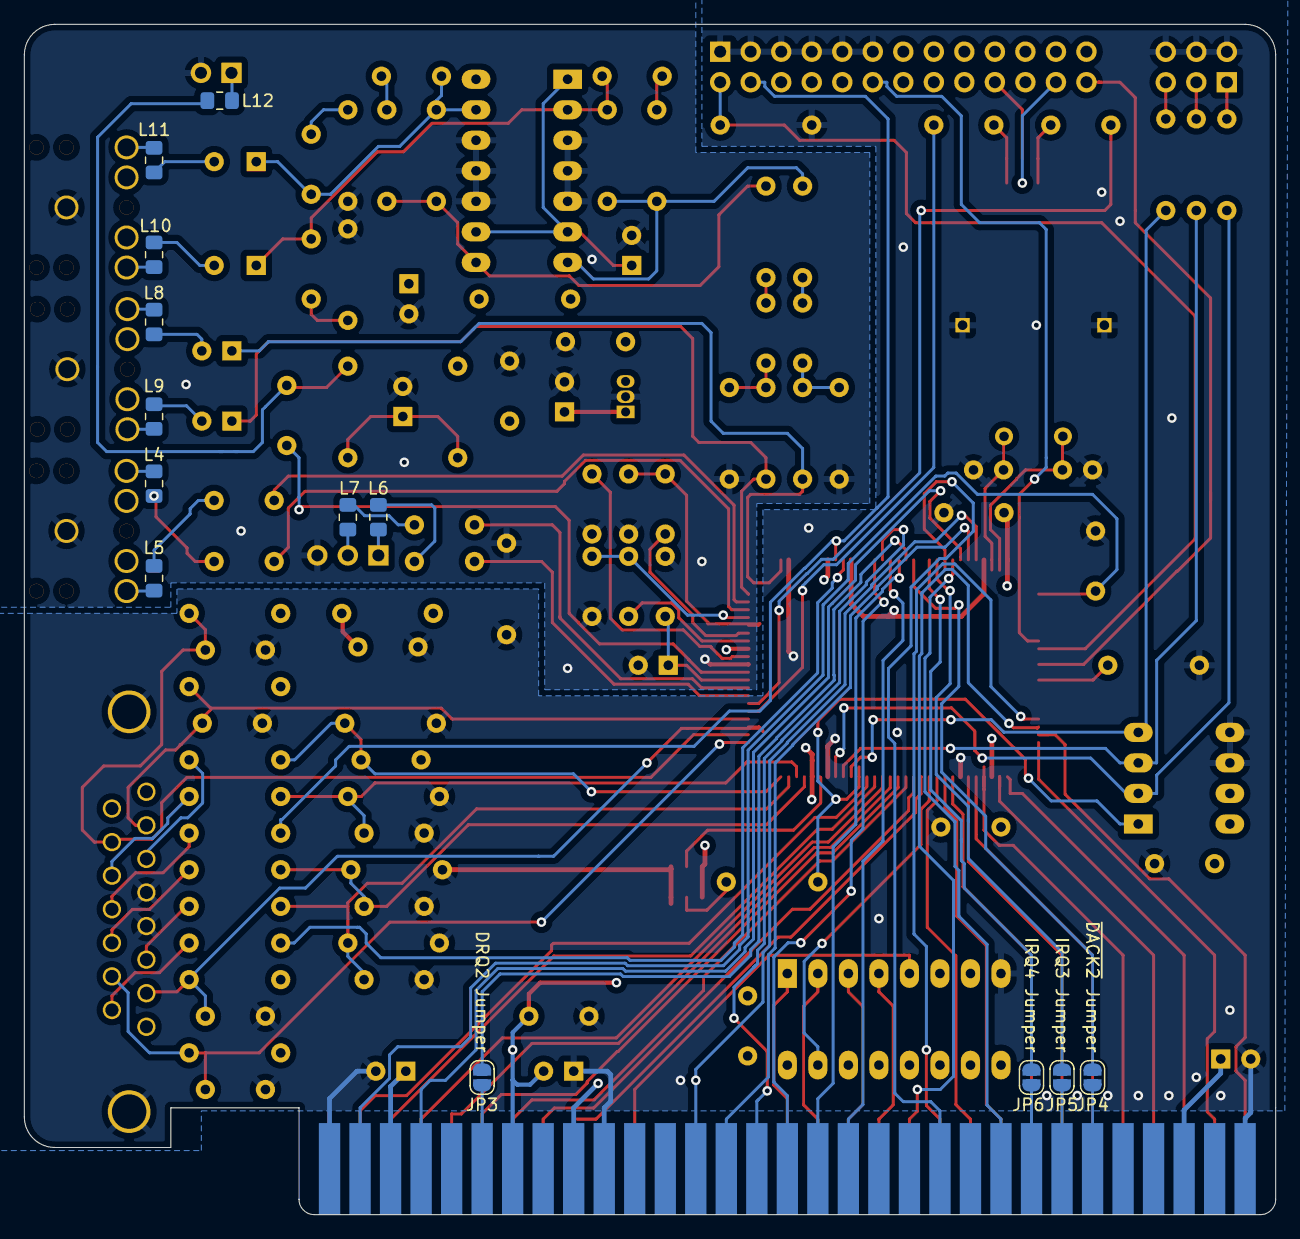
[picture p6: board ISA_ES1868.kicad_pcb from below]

Board: 4 copper layers, 104.1 x 99.1 mm, 119 parts (13 on the bottom side), 134 nets.

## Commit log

2021-05-07 Add empty project
    [ISA_ES1868.kicad_pcb, ISA_ES1868.sch]
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2021-05-08 Remove some unused connections from edge
    [ISA_ES1868.kicad_pcb, ISA_ES1868.sch]
2021-05-08 Begin drawing schematic
    [ISA_ES1868.sch]
2021-05-08 More schematics
    [ISA_ES1868.sch]
2021-05-08 Copy over more of the schematics for the audio chip
    [ISA_ES1868.sch]
2021-05-08 Partial schematic for ESS chip done
    [ISA_ES1868.sch]
2021-05-09 Completed the schematics
    [ISA_ES1868.sch]
2021-05-09 Complete schematic
    [ISA_ES1868.sch]
2021-05-09 Complete schematics, assigned footprints
    [ISA_ES1868.kicad_pcb, ISA_ES1868.sch]
2021-05-09 Change some output options
    [ISA_ES1868.kicad_pcb, ISA_ES1868.sch]
2021-05-09 start organizing things on the PCB
    [ISA_ES1868.kicad_pcb]
2021-05-09 More placement on PCB
    [ISA_ES1868.kicad_pcb]
2021-05-09 Organize external connectors
    [ISA_ES1868.kicad_pcb]
2021-05-10 Begin organizing PCB
    [ISA_ES1868.kicad_pcb, ISA_ES1868.sch]
2021-05-10 More board component placement
    [ISA_ES1868.kicad_pcb, ISA_ES1868.sch]
2021-05-10 Routed audio traces
    [ISA_ES1868.kicad_pcb, ISA_ES1868.sch]
2021-05-10 Basic power routing
    [ISA_ES1868.kicad_pcb]
2021-05-10 Commit pre-autoroute
    [ISA_ES1868.kicad_pcb]
2021-05-10 Changed some routing
    [ISA_ES1868.kicad_pcb]
2021-05-10 Change silkscreen
    [ISA_ES1868.kicad_pcb, ISA_ES1868.sch]
2021-05-10 More vias for a better ground plane
    [ISA_ES1868.kicad_pcb]
2021-05-10 More silkscreen adjustments
    [ISA_ES1868.kicad_pcb, ISA_ES1868.sch]
2021-05-10 Add description test
    [ISA_ES1868.sch]
2021-05-11 Mark some unconnected pins as unconnected
    [ISA_ES1868.sch]
2021-05-11 Fix some traces and copper areas
    [ISA_ES1868.kicad_pcb]
2021-05-11 Redo copper fills
    [ISA_ES1868.kicad_pcb]
2021-05-11 Reroute some traces
    [ISA_ES1868.kicad_pcb]
2021-05-11 Last changes to PCB
    [ISA_ES1868.kicad_pcb]
2021-05-14 Use put line out on jack
    [ISA_ES1868.kicad_pcb, ISA_ES1868.sch]
2021-05-14 Move a gnd trace
    [ISA_ES1868.kicad_pcb]
2021-05-14 Update some traces on PCB
    [ISA_ES1868.kicad_pcb]
2021-05-14 Updated PCB
    [ISA_ES1868.kicad_pcb]
2021-05-14 Moved some components on PCB
    [ISA_ES1868.kicad_pcb]
2021-05-14 Update the PCB
    [ISA_ES1868.kicad_pcb]
2021-05-14 Fixed silkscreen text
    [ISA_ES1868.kicad_pcb, ISA_ES1868.sch]
2021-05-15 changed analog ground zone
    [ISA_ES1868.kicad_pcb]
2021-05-18 Update silkscreen
    [ISA_ES1868.kicad_pcb]
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2021-05-19 Reorganized crystal on board and moved some traces
    [ISA_ES1868.kicad_pcb, ISA_ES1868.sch]
2021-05-19 Slight change to traces, add gerbers
    [ISA_ES1868.kicad_pcb]
2021-05-19 Changes to gnd plane, redone gerbers
    [ISA_ES1868.kicad_pcb]
2021-05-19 Add more gnd plane, redone gerbers
    [ISA_ES1868.kicad_pcb]
2021-05-20 Rerouting some traces
    [ISA_ES1868.kicad_pcb]
2021-05-20 Rework some traces
    [ISA_ES1868.kicad_pcb]
2021-05-20 More traces rework
    [ISA_ES1868.kicad_pcb]
2021-05-22 Moved some silkscreen
    [ISA_ES1868.kicad_pcb]
2021-05-22 Keep L/R audio traces on different sides of the board
    [ISA_ES1868.kicad_pcb]
2021-05-23 Add keystone bracket footprint from snark-barker
    [ISA_ES1868.kicad_pcb]
2021-05-23 Begin adding shape for bracket cutout, moved trace
    [ISA_ES1868.kicad_pcb]
2021-05-23 Move phone plugs a bit towards the edge
    [ISA_ES1868.kicad_pcb]
2021-05-23 Add bracket model
    [ISA_ES1868.kicad_pcb]
2021-05-23 Move some of the silkscreen
    [ISA_ES1868.kicad_pcb]
2021-05-23 Add SB DB15 connector
    [ISA_ES1868.kicad_pcb, ISA_ES1868.sch]
2021-05-23 Refill board, move some measurements
    [ISA_ES1868.kicad_pcb]
2021-05-23 Rerouted and resized some traces
    [ISA_ES1868.kicad_pcb, ISA_ES1868.sch]
2021-05-24 Move some components on the bracket
    [ISA_ES1868.kicad_pcb]
2021-05-24 Updated gerbers
    [ISA_ES1868.kicad_pcb]
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2021-05-24 Move silkscreen item
    [ISA_ES1868.kicad_pcb]
2021-05-24 Slightly move a component
    [ISA_ES1868.kicad_pcb]
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2021-05-24 Move connectors to use 9200-3 bracket
    [ISA_ES1868.kicad_pcb]
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2021-05-24 Redo joystick connections again
    [ISA_ES1868.kicad_pcb]
2021-05-24 move some traces, redo gerbers
    [ISA_ES1868.kicad_pcb]
2021-05-25 Fixed a footprint, added eth footprint
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2021-05-25 Add selection to invert channels from wavetable
    [ISA_ES1868.kicad_pcb, ISA_ES1868.sch]
2021-05-26 Replace 2 ceramic caps with electrolitic
    [ISA_ES1868.kicad_pcb, ISA_ES1868.sch]
2021-05-26 Better ground plane, redo gerber
    [ISA_ES1868.kicad_pcb]
2021-05-26 Make 12V trace a bit more hefty
    [ISA_ES1868.kicad_pcb]
2021-05-29 adjust J3 on silkscreen
    [ISA_ES1868.kicad_pcb]
2021-06-07 Slight adjustment to silkscreen
    [ISA_ES1868.kicad_pcb]
2021-06-07 Fix ES1868F unused pin symbol
2021-06-08 Better gnd plane filling
    [ISA_ES1868.kicad_pcb]
2021-06-12 Move audio jacks 0,5mm towards the edge
    [ISA_ES1868.kicad_pcb]
2021-06-17 Fix AEN pin name
2021-06-25 Add rev 1.1 gerbers
    [ISA_ES1868.kicad_pcb]
2021-07-09 Add headers for the aux_a input
    [ISA_ES1868.kicad_pcb, ISA_ES1868.sch]
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2021-07-10 Add ferrite beads at outputs and inputs, as advised by ES1869 datasheet
    [ISA_ES1868.kicad_pcb, ISA_ES1868.sch]
2021-07-11 Changed ferrite beads for audio output
    [ISA_ES1868.sch]
2021-07-11 Update PCB with new beads
    [ISA_ES1868.kicad_pcb]
2021-07-19 Modified schematic for ES1868
    [ISA_ES1868.sch]
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2021-07-19 Fix the name on the schema sheet
    [ISA_ES1868.sch]
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2022-07-25 Upgrade to KiCad 6
    [ISA_ES1868.kicad_pcb, ISA_ES1868.kicad_sch, ISA_ES1868.sch]
2023-10-13 Initial import to KiCad 7
    [ISA_ES1868.kicad_sch]
2023-10-13 Restore edge clearance
    [ISA_ES1868.kicad_pcb]
